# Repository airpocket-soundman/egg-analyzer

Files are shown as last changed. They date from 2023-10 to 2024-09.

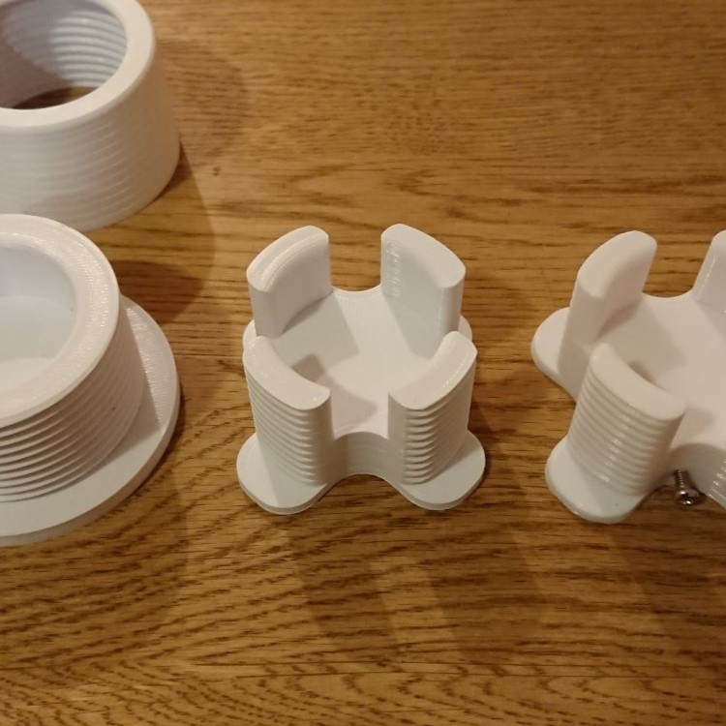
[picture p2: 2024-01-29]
img/DSC_0784_.jpg

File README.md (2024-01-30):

# egg-analyzer
卵の茹で加減を非破壊分析します。

# 開発環境
開発はArduino IDE 2.2.1を使用します。  
使用するライブラリ類は以下の通りです。  

LovyanGFX 1.1.9  

## LovyanGFX
spresenseでLovyanGFXを使用する際にはspresense向けのclass設定をインクルードする必要があります。  
LovyanGFXライブラリ内の/src/lgfx_user/LGFX_SPRESENSE_sample.hppに、spresenseでILI9341という液晶ディスプレイを使用する設定が用意されていますので今回はこれを使用します。  
設定ファイルをインクルードするには、LGFX_SPRESENSE_sample.hppをプロジェクトフォルダに事前にコピーするか、インストールしたフォルダのpathを指定します。  
ここでは、LGFX_SPRESENSE_sample.hppをプロジェクトフォルダ内にコピーして使用します。  

# Hardware

BOM
|名前|数量|備考|
|-|-|-|
|SPRESENSE メインボード|1|(switch science)[https://www.switch-science.com/products/3900]|
|SPRESENSE 拡張ボード|1|(switch science)[https://www.switch-science.com/products/3901]|
|ILI9341 2.2" TFT LCD|1|amazonなどから|
|A4988 ドライバボード|1|amazonなどから|
|Nema17 HS4023|1|[秋月電子](https://akizukidenshi.com/catalog/g/g105372/)|
|M5Stack用電流計ユニット|1|(switch science)[https://www.switch-science.com/products/6739]|
|60mmx80mm ユニバーサル基板|1||
|M2x10 ボルト|8|基板固定用|
|M3x5 皿ボルト|4|ステッピングモーター固定用|
|M3x10 ボルト|6|トップパネル固定用|
|タクトスイッチ|1|[秋月電子](https://akizukidenshi.com/catalog/g/g115660/)|
|φ2.1×φ5.5電源ジャック|1|[秋月電子](https://akizukidenshi.com/catalog/g/g106568/)|
|XHコネクタオス/メス 2P|1||
|XHコネクタオス/メス 3P|1||
|XHコネクタオス/メス 4P|4||
|XHコネクタオス/メス 5P|1||
|QIコネクタオス 2P|1||
|QIコネクタオス 8P|1||
|CASING BASE|1|3Dプリンタ出力※|
|CASING TOP MOTOR|1|3Dプリンタ出力※|
|CASING TOP DISPLAY|1|3Dプリンタ出力※|
|EGG HOLDER BASE|1|3Dプリンタ出力※|
|EGG HOLDER TOP|1|3Dプリンタ出力※|

## Spresense main board

## Spresense extention board
※ILI9431の動作電圧は3V3の為、IO voltage jumperを3V3側に設定する事  
pinout

## ILI9341
※今回使用するILI9431の動作電圧は3V3の為、IO voltage jumperを3V3側に設定する事  
接続図

## A4988 stepper motor driver

## Nema17 stepper motor

## 3D printer parts

## tact switch

# 参考ページ
## steping motor
https://forum.arduino.cc/t/stepper-motor-basics/275223  
https://iot.keicode.com/arduino/arduino-stepper-motor-a4988.php

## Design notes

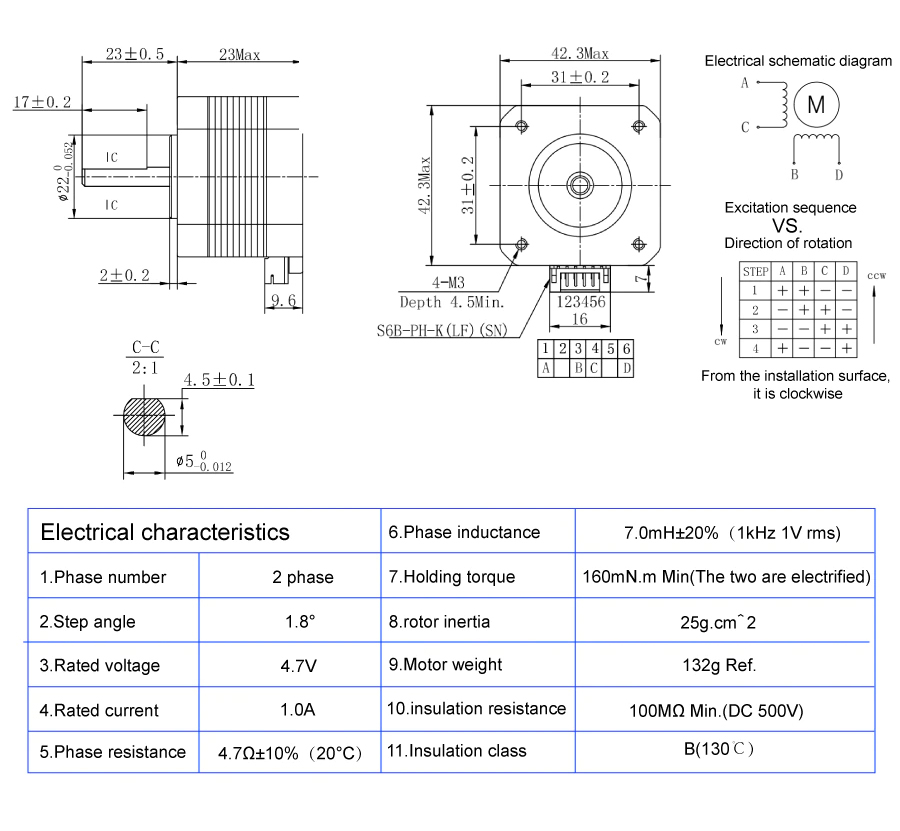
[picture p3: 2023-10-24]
img/Nema17 17HS4023.jpg

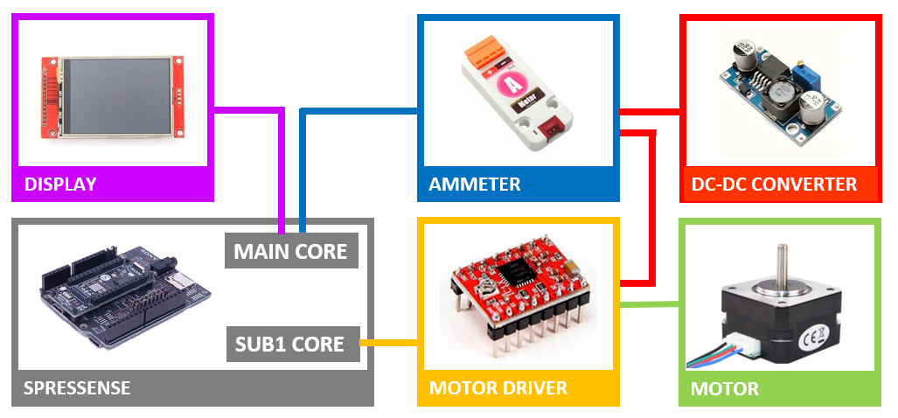
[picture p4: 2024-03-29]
img/構成図.png

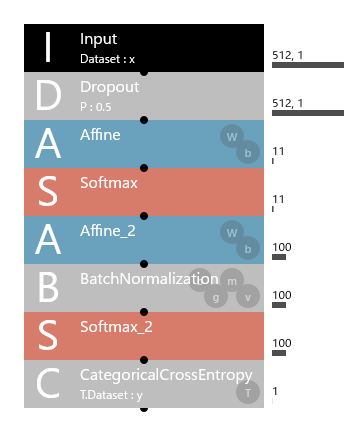
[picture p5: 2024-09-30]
NNC/rawfiles/20240128学習用最終データ/3class_onsen.files/20240128_211929/network.png

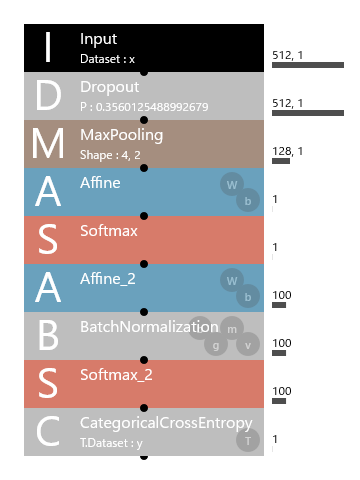
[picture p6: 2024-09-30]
NNC/rawfiles/20240128学習用最終データ/3class_onsen.files/20240128_223451/network.png

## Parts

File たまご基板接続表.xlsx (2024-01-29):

spressens | A4988 | MOTOR | AMMETER | DISPLAY | SW | V12 | STEPDOWN
RX | STEP
TX | DIR
 | B2 | RED
 | A2 | BLUE
 | A1 | GREEN
 | B1 | BLACK
3.3V | VDD |  | VCC | AREF
GND | GND |  | GND | GND |  | GND | in/out -
 | VMOT |  | -
 | GND
 |  |  | + |  |  | OUT | in +
D15 |  |  | SCL
D14 |  |  | SDA
D13 |  |  |  | SCL
D12 |  |  |  | MISO
D11 |  |  |  | MOSI
D10 |  |  |  | CS
D09 |  |  |  | DC
D08 |  |  |  | RST
D04 |  |  |  |  | IN
VOUT |  |  |  |  |  |  | out +

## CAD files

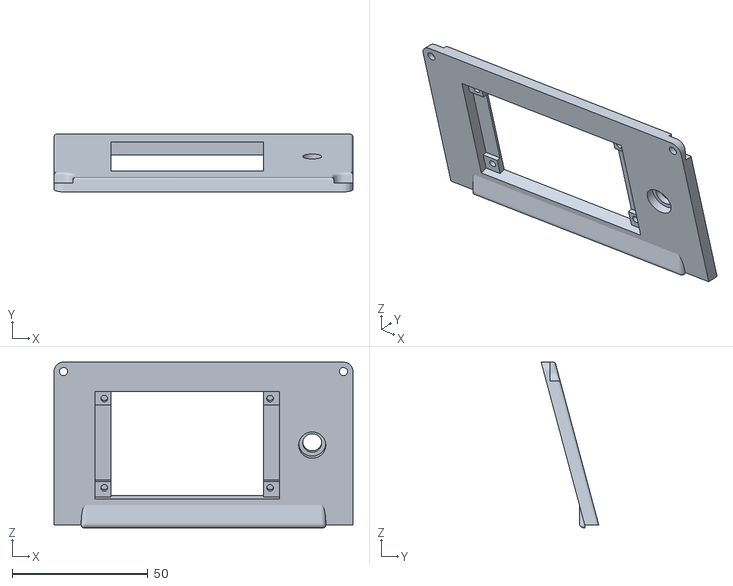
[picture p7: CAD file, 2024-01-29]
stls/top_display v5.stl
110.0 x 21.3 x 61.0

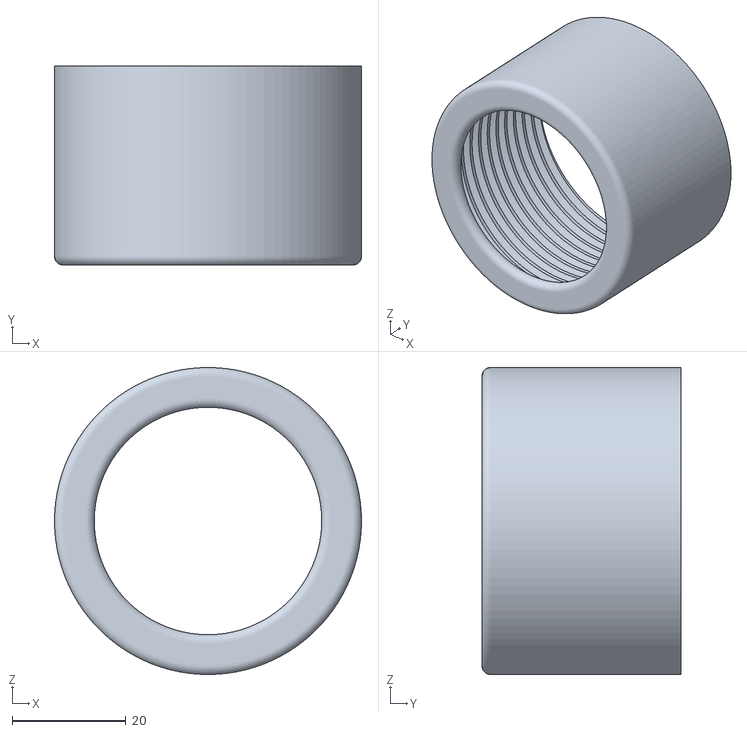
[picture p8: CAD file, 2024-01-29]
stls/egg holoder2 upper v10.stl
54.0 x 35.0 x 54.0

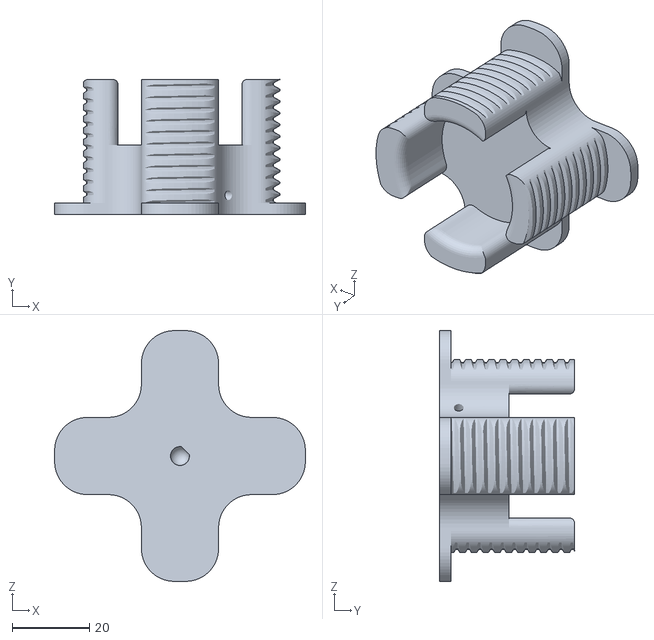
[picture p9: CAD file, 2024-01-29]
stls/egg holder3 v5.stl
65.0 x 35.0 x 65.0

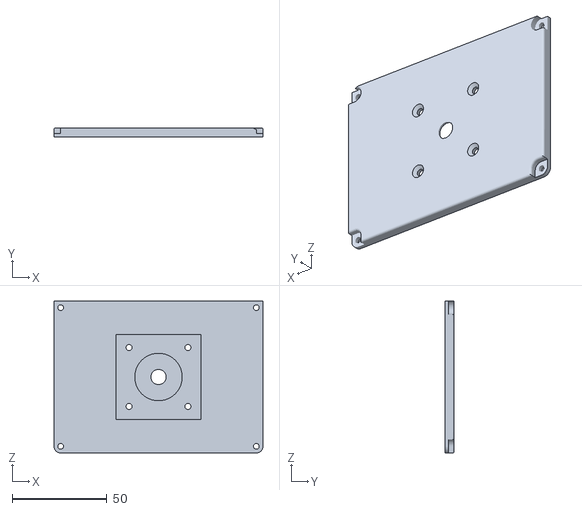
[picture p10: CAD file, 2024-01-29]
stls/top_motor v6.stl
110.0 x 5.00 x 80.0

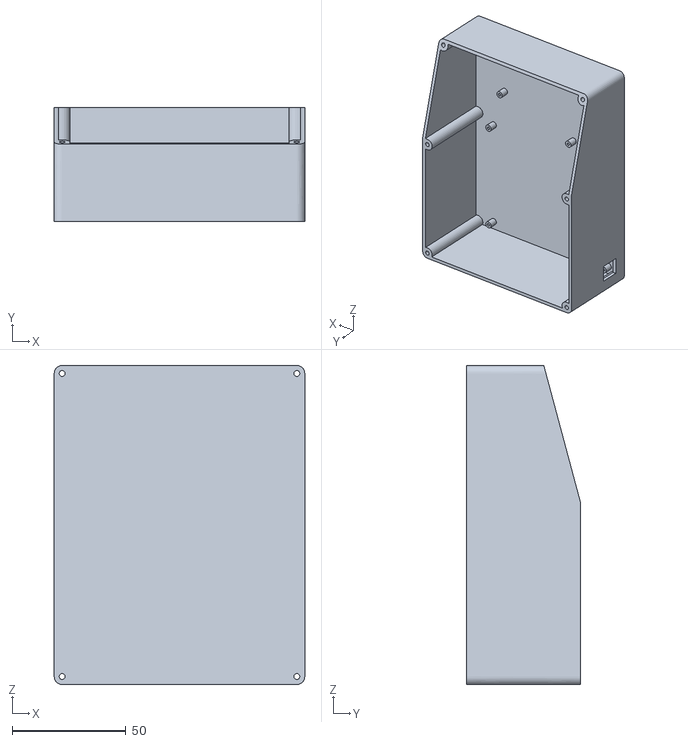
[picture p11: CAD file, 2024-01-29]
stls/case_base v3.stl
110.0 x 50.0 x 140.0

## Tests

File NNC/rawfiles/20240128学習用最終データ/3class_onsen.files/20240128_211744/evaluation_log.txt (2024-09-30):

2024-01-28 22:21:44,733 Evaluation process is started.
python "C:\Users\yamas\Desktop\tools\neural_network_console\libs\Python\Lib\site-packages\nnabla\utils\cli\cli.py" forward
	-c "C:\Users\yamas\Desktop\20240128\3class_onsen.files\20240128_211744\results.nnp"
	-d "C:\Users\yamas\Desktop\20240128\egg_data_set_valid_3class_onsen.csv"
	-o "C:\Users\yamas\Desktop\20240128\3class_onsen.files\20240128_211744"
	--replace_path
2024-01-28 22:21:46,946 [nnabla]: [CALLBACK]: Exec forward on local
2024-01-28 22:21:46,962 [nnabla]: Using context "Context(backend=['cpu:float'], array_class='CpuCachedArray', device_id='')"
2024-01-28 22:21:47,167 [nnabla]: data 64 / 1200
2024-01-28 22:21:47,340 [nnabla]: data 128 / 1200
2024-01-28 22:21:47,524 [nnabla]: data 192 / 1200
2024-01-28 22:21:47,702 [nnabla]: data 256 / 1200
2024-01-28 22:21:47,874 [nnabla]: data 320 / 1200
2024-01-28 22:21:48,051 [nnabla]: data 384 / 1200
2024-01-28 22:21:48,193 [nnabla]: data 448 / 1200
2024-01-28 22:21:48,347 [nnabla]: data 512 / 1200
2024-01-28 22:21:48,526 [nnabla]: data 576 / 1200
2024-01-28 22:21:48,703 [nnabla]: data 640 / 1200
2024-01-28 22:21:48,876 [nnabla]: data 704 / 1200
2024-01-28 22:21:49,050 [nnabla]: data 768 / 1200
2024-01-28 22:21:49,227 [nnabla]: data 832 / 1200
2024-01-28 22:21:49,406 [nnabla]: data 896 / 1200
2024-01-28 22:21:49,584 [nnabla]: data 960 / 1200
2024-01-28 22:21:49,759 [nnabla]: data 1024 / 1200
2024-01-28 22:21:49,936 [nnabla]: data 1088 / 1200
2024-01-28 22:21:50,111 [nnabla]: data 1152 / 1200
2024-01-28 22:21:50,251 [nnabla]: data 1200 / 1200
2024-01-28 22:21:50,267 [nnabla]: Forward Completed.
NNabla command line interface (Version:1.33.1, Build:230206070804, Callback:NNabla SSH callback module.)

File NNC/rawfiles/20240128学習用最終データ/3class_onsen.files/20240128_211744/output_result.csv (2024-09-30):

x:egg_data | y:state | y'__0 | y'__1 | y'__2 | y'__3 | y'__4 | y'__5 | y'__6 | y'__7 | y'__8 | y'__9 | y'__10 | y'__11 | y'__12 | y'__13 | y'__14 | y'__15 | y'__16 | y'__17 | y'__18 | y'__19 | y'__20 | y'__21 | y'__22 | y'__23 | y'__24 | y'__25 | y'__26 | y'__27 | y'__28 | y'__29 | y'__30 | y'__31 | y'__32 | y'__33 | y'__34 | y'__35 | y'__36 | y'__37 | y'__38 | y'__39 | y'__40 | y'__41 | y'__42 | y'__43 | y'__44 | y'__45 | y'__46 | y'__47 | y'__48 | y'__49 | y'__50 | y'__51 | y'__52 | y'__53 | y'__54 | y'__55 | y'__56 | y'__57
C:\Users\yamas\Desktop\20240128\raw0_9x100\fft_060.csv | 0 | 0.92927456 | 0.0018030053 | 0.0022519156 | 0.0006740404 | 0.0006867987 | 0.0007027974 | 0.00068848603 | 0.0006884276 | 0.00069293234 | 0.00069257786 | 0.00067942415 | 0.0006645207 | 0.00069902604 | 0.000694238 | 0.0006832155 | 0.0006840654 | 0.0006793986 | 0.0007164532 | 0.00072102505 | 0.000685254 | 0.00067573186 | 0.00066117983 | 0.00068182714 | 0.0007017419 | 0.00068063627 | 0.00067919196 | 0.0007097714 | 0.0007231526 | 0.0006986092 | 0.00068962516 | 0.00068811513 | 0.00065855443 | 0.00069438835 | 0.00066847424 | 0.00066585414 | 0.0006784439 | 0.0007019413 | 0.00068379496 | 0.00070631824 |
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

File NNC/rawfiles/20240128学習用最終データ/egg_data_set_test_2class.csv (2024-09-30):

x:egg_data | y:state
./raw0_9x100/fft_000.csv | 0
./raw0_9x100/fft_001.csv | 0
./raw0_9x100/fft_002.csv | 0
./raw0_9x100/fft_003.csv | 0
./raw0_9x100/fft_004.csv | 0
./raw0_9x100/fft_005.csv | 0
./raw0_9x100/fft_006.csv | 0
./raw0_9x100/fft_007.csv | 0
./raw0_9x100/fft_008.csv | 0
./raw0_9x100/fft_009.csv | 0
./raw0_9x100/fft_010.csv | 0
./raw0_9x100/fft_011.csv | 0
./raw0_9x100/fft_012.csv | 0
./raw0_9x100/fft_013.csv | 0
./raw0_9x100/fft_014.csv | 0
./raw0_9x100/fft_015.csv | 0
./raw0_9x100/fft_016.csv | 0
./raw0_9x100/fft_017.csv | 0
./raw0_9x100/fft_018.csv | 0
./raw0_9x100/fft_019.csv | 0
./raw0_9x100/fft_020.csv | 0
./raw0_9x100/fft_021.csv | 0
./raw0_9x100/fft_022.csv | 0
./raw0_9x100/fft_023.csv | 0
./raw0_9x100/fft_024.csv | 0
./raw0_9x100/fft_025.csv | 0
./raw0_9x100/fft_026.csv | 0
./raw0_9x100/fft_027.csv | 0
./raw0_9x100/fft_028.csv | 0
./raw0_9x100/fft_029.csv | 0
./raw0_9x100/fft_030.csv | 0
./raw0_9x100/fft_031.csv | 0
./raw0_9x100/fft_032.csv | 0
./raw0_9x100/fft_033.csv | 0
./raw0_9x100/fft_034.csv | 0
./raw0_9x100/fft_035.csv | 0
./raw0_9x100/fft_036.csv | 0
./raw0_9x100/fft_037.csv | 0
./raw0_9x100/fft_038.csv | 0
./raw0_9x100/fft_039.csv | 0
./raw0_9x100/fft_040.csv | 0
./raw0_9x100/fft_041.csv | 0
./raw0_9x100/fft_042.csv | 0
./raw0_9x100/fft_043.csv | 0
./raw0_9x100/fft_044.csv | 0
./raw0_9x100/fft_045.csv | 0
./raw0_9x100/fft_046.csv | 0
./raw0_9x100/fft_047.csv | 0
./raw0_9x100/fft_048.csv | 0
./raw0_9x100/fft_049.csv | 0
./raw0_9x100/fft_050.csv | 0
./raw0_9x100/fft_051.csv | 0
./raw0_9x100/fft_052.csv | 0
./raw0_9x100/fft_053.csv | 0
./raw0_9x100/fft_054.csv | 0
./raw0_9x100/fft_055.csv | 0
./raw0_9x100/fft_056.csv | 0
./raw0_9x100/fft_057.csv | 0
./raw0_9x100/fft_058.csv | 0
./raw0_9x100/fft_059.csv | 0
./raw0_9x100/fft_100.csv | 0
./raw0_9x100/fft_101.csv | 0
./raw0_9x100/fft_102.csv | 0
./raw0_9x100/fft_103.csv | 0
./raw0_9x100/fft_104.csv | 0
./raw0_9x100/fft_105.csv | 0
./raw0_9x100/fft_106.csv | 0
./raw0_9x100/fft_107.csv | 0
./raw0_9x100/fft_108.csv | 0
./raw0_9x100/fft_109.csv | 0
./raw0_9x100/fft_110.csv | 0
./raw0_9x100/fft_111.csv | 0
./raw0_9x100/fft_112.csv | 0
./raw0_9x100/fft_113.csv | 0
./raw0_9x100/fft_114.csv | 0
./raw0_9x100/fft_115.csv | 0
./raw0_9x100/fft_116.csv | 0
./raw0_9x100/fft_117.csv | 0
./raw0_9x100/fft_118.csv | 0
./raw0_9x100/fft_119.csv | 0
./raw0_9x100/fft_120.csv | 0
./raw0_9x100/fft_121.csv | 0
./raw0_9x100/fft_122.csv | 0
./raw0_9x100/fft_123.csv | 0
./raw0_9x100/fft_124.csv | 0
./raw0_9x100/fft_125.csv | 0
./raw0_9x100/fft_126.csv | 0
./raw0_9x100/fft_127.csv | 0
./raw0_9x100/fft_128.csv | 0
./raw0_9x100/fft_129.csv | 0
./raw0_9x100/fft_130.csv | 0
./raw0_9x100/fft_131.csv | 0
./raw0_9x100/fft_132.csv | 0
./raw0_9x100/fft_133.csv | 0
./raw0_9x100/fft_134.csv | 0
./raw0_9x100/fft_135.csv | 0
./raw0_9x100/fft_136.csv | 0
./raw0_9x100/fft_137.csv | 0
./raw0_9x100/fft_138.csv | 0
./raw0_9x100/fft_139.csv | 0
./raw0_9x100/fft_140.csv | 0
./raw0_9x100/fft_141.csv | 0
./raw0_9x100/fft_142.csv | 0
./raw0_9x100/fft_143.csv | 0
./raw0_9x100/fft_144.csv | 0
./raw0_9x100/fft_145.csv | 0
./raw0_9x100/fft_146.csv | 0
./raw0_9x100/fft_147.csv | 0
./raw0_9x100/fft_148.csv | 0
./raw0_9x100/fft_149.csv | 0
./raw0_9x100/fft_150.csv | 0
./raw0_9x100/fft_151.csv | 0
./raw0_9x100/fft_152.csv | 0
./raw0_9x100/fft_153.csv | 0
./raw0_9x100/fft_154.csv | 0
./raw0_9x100/fft_155.csv | 0
./raw0_9x100/fft_156.csv | 0
./raw0_9x100/fft_157.csv | 0
./raw0_9x100/fft_158.csv | 0
./raw0_9x100/fft_159.csv | 0
./raw0_9x100/fft_200.csv | 0
./raw0_9x100/fft_201.csv | 0
./raw0_9x100/fft_202.csv | 0
./raw0_9x100/fft_203.csv | 0
./raw0_9x100/fft_204.csv | 0
./raw0_9x100/fft_205.csv | 0
./raw0_9x100/fft_206.csv | 0
./raw0_9x100/fft_207.csv | 0
./raw0_9x100/fft_208.csv | 0
./raw0_9x100/fft_209.csv | 0
./raw0_9x100/fft_210.csv | 0
./raw0_9x100/fft_211.csv | 0
./raw0_9x100/fft_212.csv | 0
./raw0_9x100/fft_213.csv | 0
./raw0_9x100/fft_214.csv | 0
./raw0_9x100/fft_215.csv | 0
./raw0_9x100/fft_216.csv | 0
./raw0_9x100/fft_217.csv | 0
./raw0_9x100/fft_218.csv | 0
./raw0_9x100/fft_219.csv | 0
./raw0_9x100/fft_220.csv | 0
./raw0_9x100/fft_221.csv | 0
./raw0_9x100/fft_222.csv | 0
./raw0_9x100/fft_223.csv | 0
./raw0_9x100/fft_224.csv | 0
./raw0_9x100/fft_225.csv | 0
./raw0_9x100/fft_226.csv | 0
./raw0_9x100/fft_227.csv | 0
./raw0_9x100/fft_228.csv | 0
./raw0_9x100/fft_229.csv | 0
./raw0_9x100/fft_230.csv | 0
./raw0_9x100/fft_231.csv | 0
./raw0_9x100/fft_232.csv | 0
./raw0_9x100/fft_233.csv | 0
./raw0_9x100/fft_234.csv | 0
./raw0_9x100/fft_235.csv | 0
./raw0_9x100/fft_236.csv | 0
./raw0_9x100/fft_237.csv | 0
./raw0_9x100/fft_238.csv | 0
./raw0_9x100/fft_239.csv | 0
./raw0_9x100/fft_240.csv | 0
./raw0_9x100/fft_241.csv | 0
./raw0_9x100/fft_242.csv | 0
./raw0_9x100/fft_243.csv | 0
./raw0_9x100/fft_244.csv | 0
./raw0_9x100/fft_245.csv | 0
./raw0_9x100/fft_246.csv | 0
./raw0_9x100/fft_247.csv | 0
./raw0_9x100/fft_248.csv | 0
./raw0_9x100/fft_249.csv | 0
./raw0_9x100/fft_250.csv | 0
./raw0_9x100/fft_251.csv | 0
./raw0_9x100/fft_252.csv | 0
./raw0_9x100/fft_253.csv | 0
./raw0_9x100/fft_254.csv | 0
./raw0_9x100/fft_255.csv | 0
./raw0_9x100/fft_256.csv | 0
./raw0_9x100/fft_257.csv | 0
./raw0_9x100/fft_258.csv | 0
./raw0_9x100/fft_259.csv | 0
./raw0_9x100/fft_300.csv | 0
./raw0_9x100/fft_301.csv | 0
./raw0_9x100/fft_302.csv | 0
./raw0_9x100/fft_303.csv | 0
./raw0_9x100/fft_304.csv | 0
./raw0_9x100/fft_305.csv | 0
./raw0_9x100/fft_306.csv | 0
./raw0_9x100/fft_307.csv | 0
./raw0_9x100/fft_308.csv | 0
./raw0_9x100/fft_309.csv | 0
./raw0_9x100/fft_310.csv | 0
./raw0_9x100/fft_311.csv | 0
./raw0_9x100/fft_312.csv | 0
./raw0_9x100/fft_313.csv | 0
./raw0_9x100/fft_314.csv | 0
./raw0_9x100/fft_315.csv | 0
./raw0_9x100/fft_316.csv | 0
./raw0_9x100/fft_317.csv | 0
./raw0_9x100/fft_318.csv | 0
./raw0_9x100/fft_319.csv | 0
./raw0_9x100/fft_320.csv | 0
./raw0_9x100/fft_321.csv | 0
./raw0_9x100/fft_322.csv | 0
./raw0_9x100/fft_323.csv | 0
./raw0_9x100/fft_324.csv | 0
./raw0_9x100/fft_325.csv | 0
./raw0_9x100/fft_326.csv | 0
./raw0_9x100/fft_327.csv | 0
./raw0_9x100/fft_328.csv | 0
./raw0_9x100/fft_329.csv | 0
./raw0_9x100/fft_330.csv | 0
./raw0_9x100/fft_331.csv | 0
./raw0_9x100/fft_332.csv | 0
./raw0_9x100/fft_333.csv | 0
./raw0_9x100/fft_334.csv | 0
./raw0_9x100/fft_335.csv | 0
./raw0_9x100/fft_336.csv | 0
./raw0_9x100/fft_337.csv | 0
./raw0_9x100/fft_338.csv | 0
./raw0_9x100/fft_339.csv | 0
./raw0_9x100/fft_340.csv | 0
./raw0_9x100/fft_341.csv | 0
./raw0_9x100/fft_342.csv | 0
./raw0_9x100/fft_343.csv | 0
./raw0_9x100/fft_344.csv | 0
./raw0_9x100/fft_345.csv | 0
./raw0_9x100/fft_346.csv | 0
./raw0_9x100/fft_347.csv | 0
./raw0_9x100/fft_348.csv | 0
./raw0_9x100/fft_349.csv | 0
./raw0_9x100/fft_350.csv | 0
./raw0_9x100/fft_351.csv | 0
./raw0_9x100/fft_352.csv | 0
./raw0_9x100/fft_353.csv | 0
./raw0_9x100/fft_354.csv | 0
./raw0_9x100/fft_355.csv | 0
./raw0_9x100/fft_356.csv | 0
./raw0_9x100/fft_357.csv | 0
./raw0_9x100/fft_358.csv | 0
./raw0_9x100/fft_359.csv | 0
./raw0_9x100/fft_400.csv | 0
./raw0_9x100/fft_401.csv | 0
./raw0_9x100/fft_402.csv | 0
./raw0_9x100/fft_403.csv | 0
./raw0_9x100/fft_404.csv | 0
./raw0_9x100/fft_405.csv | 0
./raw0_9x100/fft_406.csv | 0
./raw0_9x100/fft_407.csv | 0
./raw0_9x100/fft_408.csv | 0
./raw0_9x100/fft_409.csv | 0
./raw0_9x100/fft_410.csv | 0
./raw0_9x100/fft_411.csv | 0
./raw0_9x100/fft_412.csv | 0
./raw0_9x100/fft_413.csv | 0
./raw0_9x100/fft_414.csv | 0
./raw0_9x100/fft_415.csv | 0
./raw0_9x100/fft_416.csv | 0
./raw0_9x100/fft_417.csv | 0
./raw0_9x100/fft_418.csv | 0
./raw0_9x100/fft_419.csv | 0
./raw0_9x100/fft_420.csv | 0
./raw0_9x100/fft_421.csv | 0
./raw0_9x100/fft_422.csv | 0
./raw0_9x100/fft_423.csv | 0
./raw0_9x100/fft_424.csv | 0
./raw0_9x100/fft_425.csv | 0
./raw0_9x100/fft_426.csv | 0
./raw0_9x100/fft_427.csv | 0
./raw0_9x100/fft_428.csv | 0
./raw0_9x100/fft_429.csv | 0
./raw0_9x100/fft_430.csv | 0
./raw0_9x100/fft_431.csv | 0
./raw0_9x100/fft_432.csv | 0
./raw0_9x100/fft_433.csv | 0
./raw0_9x100/fft_434.csv | 0
./raw0_9x100/fft_435.csv | 0
./raw0_9x100/fft_436.csv | 0
./raw0_9x100/fft_437.csv | 0
./raw0_9x100/fft_438.csv | 0
./raw0_9x100/fft_439.csv | 0
./raw0_9x100/fft_440.csv | 0
./raw0_9x100/fft_441.csv | 0
./raw0_9x100/fft_442.csv | 0
./raw0_9x100/fft_443.csv | 0
./raw0_9x100/fft_444.csv | 0
./raw0_9x100/fft_445.csv | 0
./raw0_9x100/fft_446.csv | 0
./raw0_9x100/fft_447.csv | 0
./raw0_9x100/fft_448.csv | 0
./raw0_9x100/fft_449.csv | 0
./raw0_9x100/fft_450.csv | 0
./raw0_9x100/fft_451.csv | 0
./raw0_9x100/fft_452.csv | 0
./raw0_9x100/fft_453.csv | 0
./raw0_9x100/fft_454.csv | 0
./raw0_9x100/fft_455.csv | 0
./raw0_9x100/fft_456.csv | 0
./raw0_9x100/fft_457.csv | 0
./raw0_9x100/fft_458.csv | 0
./raw0_9x100/fft_459.csv | 0
./raw0_9x100/fft_500.csv | 0
./raw0_9x100/fft_501.csv | 0
./raw0_9x100/fft_502.csv | 0
./raw0_9x100/fft_503.csv | 0
./raw0_9x100/fft_504.csv | 0
./raw0_9x100/fft_505.csv | 0
./raw0_9x100/fft_506.csv | 0
./raw0_9x100/fft_507.csv | 0
./raw0_9x100/fft_508.csv | 0
./raw0_9x100/fft_509.csv | 0
./raw0_9x100/fft_510.csv | 0
./raw0_9x100/fft_511.csv | 0
./raw0_9x100/fft_512.csv | 0
./raw0_9x100/fft_513.csv | 0
./raw0_9x100/fft_514.csv | 0
./raw0_9x100/fft_515.csv | 0
./raw0_9x100/fft_516.csv | 0
./raw0_9x100/fft_517.csv | 0
./raw0_9x100/fft_518.csv | 0
./raw0_9x100/fft_519.csv | 0
./raw0_9x100/fft_520.csv | 0
./raw0_9x100/fft_521.csv | 0
./raw0_9x100/fft_522.csv | 0
./raw0_9x100/fft_523.csv | 0
./raw0_9x100/fft_524.csv | 0
./raw0_9x100/fft_525.csv | 0
./raw0_9x100/fft_526.csv | 0
./raw0_9x100/fft_527.csv | 0
./raw0_9x100/fft_528.csv | 0
./raw0_9x100/fft_529.csv | 0
./raw0_9x100/fft_530.csv | 0
./raw0_9x100/fft_531.csv | 0
./raw0_9x100/fft_532.csv | 0
./raw0_9x100/fft_533.csv | 0
./raw0_9x100/fft_534.csv | 0
./raw0_9x100/fft_535.csv | 0
./raw0_9x100/fft_536.csv | 0
./raw0_9x100/fft_537.csv | 0
./raw0_9x100/fft_538.csv | 0
./raw0_9x100/fft_539.csv | 0
./raw0_9x100/fft_540.csv | 0
./raw0_9x100/fft_541.csv | 0
./raw0_9x100/fft_542.csv | 0
./raw0_9x100/fft_543.csv | 0
./raw0_9x100/fft_544.csv | 0
./raw0_9x100/fft_545.csv | 0
./raw0_9x100/fft_546.csv | 0
./raw0_9x100/fft_547.csv | 0
./raw0_9x100/fft_548.csv | 0
./raw0_9x100/fft_549.csv | 0
./raw0_9x100/fft_550.csv | 0
./raw0_9x100/fft_551.csv | 0
./raw0_9x100/fft_552.csv | 0
./raw0_9x100/fft_553.csv | 0
./raw0_9x100/fft_554.csv | 0
./raw0_9x100/fft_555.csv | 0
./raw0_9x100/fft_556.csv | 0
./raw0_9x100/fft_557.csv | 0
./raw0_9x100/fft_558.csv | 0
./raw0_9x100/fft_559.csv | 0
./raw0_9x100/fft_600.csv | 0
./raw0_9x100/fft_601.csv | 0
./raw0_9x100/fft_602.csv | 0
./raw0_9x100/fft_603.csv | 0
./raw0_9x100/fft_604.csv | 0
./raw0_9x100/fft_605.csv | 0
./raw0_9x100/fft_606.csv | 0
./raw0_9x100/fft_607.csv | 0
./raw0_9x100/fft_608.csv | 0
./raw0_9x100/fft_609.csv | 0
./raw0_9x100/fft_610.csv | 0
./raw0_9x100/fft_611.csv | 0
./raw0_9x100/fft_612.csv | 0
./raw0_9x100/fft_613.csv | 0
./raw0_9x100/fft_614.csv | 0
./raw0_9x100/fft_615.csv | 0
./raw0_9x100/fft_616.csv | 0
./raw0_9x100/fft_617.csv | 0
./raw0_9x100/fft_618.csv | 0
./raw0_9x100/fft_619.csv | 0
./raw0_9x100/fft_620.csv | 0
./raw0_9x100/fft_621.csv | 0
./raw0_9x100/fft_622.csv | 0
./raw0_9x100/fft_623.csv | 0
./raw0_9x100/fft_624.csv | 0
./raw0_9x100/fft_625.csv | 0
./raw0_9x100/fft_626.csv | 0
./raw0_9x100/fft_627.csv | 0
./raw0_9x100/fft_628.csv | 0
./raw0_9x100/fft_629.csv | 0
./raw0_9x100/fft_630.csv | 0
./raw0_9x100/fft_631.csv | 0
./raw0_9x100/fft_632.csv | 0
./raw0_9x100/fft_633.csv | 0
./raw0_9x100/fft_634.csv | 0
./raw0_9x100/fft_635.csv | 0
./raw0_9x100/fft_636.csv | 0
./raw0_9x100/fft_637.csv | 0
./raw0_9x100/fft_638.csv | 0
./raw0_9x100/fft_639.csv | 0
./raw0_9x100/fft_640.csv | 0
./raw0_9x100/fft_641.csv | 0
./raw0_9x100/fft_642.csv | 0
./raw0_9x100/fft_643.csv | 0
./raw0_9x100/fft_644.csv | 0
./raw0_9x100/fft_645.csv | 0
./raw0_9x100/fft_646.csv | 0
./raw0_9x100/fft_647.csv | 0
./raw0_9x100/fft_648.csv | 0
./raw0_9x100/fft_649.csv | 0
./raw0_9x100/fft_650.csv | 0
./raw0_9x100/fft_651.csv | 0
./raw0_9x100/fft_652.csv | 0
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

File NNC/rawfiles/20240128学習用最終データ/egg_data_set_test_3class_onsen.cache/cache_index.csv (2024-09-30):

cache_00000000_00000099.npy | 100
cache_00000100_00000199.npy | 100
cache_00000200_00000299.npy | 100
cache_00000300_00000399.npy | 100
cache_00000400_00000499.npy | 100
cache_00000500_00000599.npy | 100
cache_00000600_00000699.npy | 100
cache_00000700_00000799.npy | 100
cache_00000800_00000899.npy | 100
cache_00000900_00000999.npy | 100
cache_00001000_00001099.npy | 100
cache_00001100_00001199.npy | 100
cache_00001200_00001299.npy | 100
cache_00001300_00001399.npy | 100
cache_00001400_00001499.npy | 100
cache_00001500_00001599.npy | 100
cache_00001600_00001699.npy | 100
cache_00001700_00001799.npy | 100

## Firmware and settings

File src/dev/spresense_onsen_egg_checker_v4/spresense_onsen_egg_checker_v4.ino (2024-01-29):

//subcore1 : spresense_stepper_ameter_subcore_v5.ino

#ifdef SUBCORE
#error "Core selection is wrong!!"
#endif

#include <Arduino.h>
#include <Wire.h>
#include "arduinoFFT.h"

#include <MP.h>
int subcore1   = 1;               //使用するサブコア

#include "LGFX_SPRESENSE_sample.hpp"
static LGFX lcd;                  //ディスプレイインスタンス作成


#include <DNNRT.h>
DNNRT dnnrt;

#include <SDHCI.h>
#include <Flash.h>
SDClass SD;                       /**< SDClass object */ 
File nnbFile;
File myFile;

//ファイル保存用変数
int number = 0;       //測定の通し番号

// 測定条件
#define TOTAL_MESUREMENTS   1024    //測定回数
#define MESUREMENT_CYCLE    2500    //測定頻度 us秒/回
#define MESURE_START_DELAY  250000   //モータースタートから測定開始までのディレイタイム　usec
int freq = 1000000 / MESUREMENT_CYCLE;

//FFT用
double vReal[TOTAL_MESUREMENTS];  // vReal[]にサンプリングしたデーターを入れる
double vImag[TOTAL_MESUREMENTS];  // 虚数部
arduinoFFT FFT = arduinoFFT(vReal, vImag, TOTAL_MESUREMENTS, freq);  // FFTオブジェクトを作る


#include "ammeter.h"
Ammeter ammeter;                  /**Ameter object**/
double am_value[TOTAL_MESUREMENTS];
int elapsed_time[TOTAL_MESUREMENTS];

//gpio 定義
const int SW1Pin = 4;
const int SW2Pin = 6;
const int SW3Pin = 5;
const int SW4Pin = 7;
const int SW5Pin = 3;

//switch state管理用
int SW1State    = LOW;
int SW2State    = LOW;
int SW3State    = LOW;
int SW4State    = LOW;
int SW5State    = LOW;
int SW1StateOld = LOW;
int SW2StateOld = LOW;
int SW3StateOld = LOW;
int SW4StateOld = LOW;
int SW5StateOld = LOW;

void setup() {
//nnb file open
  SD.begin();
  nnbFile = SD.open("model.nnb");                     //学習済みデータ読み込み
  if (!nnbFile) {
    Serial.println("model.nnb is not found");
    while(1);
  }
  
  int ret = dnnrt.begin(nnbFile);
  if (ret <0){
    Serial.println("DNNRT begin fail: " + String(ret));
    while(1);
  }

  Wire.begin();                 //i2cを有効化
  Wire.setClock(1000000);       //standart mode:100000, fast mode:400000, fast mode plus:1000000, high speed mode:3400000
  Serial.begin(115200);         //USBシリアル通信を有効化

  ret = 0;
  ret = MP.begin(subcore1);                           //subcore1を起動
  if (ret < 0) {                                      //subcore起動失敗時の表示
    MPLog("MP.begin(%d) error = %d\n", 1, ret);
  }

  //ameter 設定
  ammeter.setMode(SINGLESHOT);
  ammeter.setRate(RATE_860);    //8,16,32,64,128(defo),250,475,860
  ammeter.setGain(PAG_2048);
//  hope = page512_volt / ammeter.resolution;
  // | PAG      | Max Input Voltage(V) |
  // | PAG_6144 |        128           |
  // | PAG_4096 |        64            |
  // | PAG_2048 |        32            |
  // | PAG_512  |        16            |
  // | PAG_256  |        8             |

  //Switch pin 設定
  pinMode(SW1Pin, INPUT_PULLUP);
  pinMode(SW2Pin, INPUT_PULLUP);
  pinMode(SW3Pin, INPUT_PULLUP);
  pinMode(SW4Pin, INPUT_PULLUP);
  pinMode(SW5Pin, INPUT_PULLUP);

  lcd.init();                       //ili9431を初期化
  lcd.setRotation(1);               //右へ90°回転
  lcd.setFont(&fonts::Font0);
}

void loop() {

  SW1StateOld = SW1State;
  SW1State = digitalRead(SW1Pin);
  SW2StateOld = SW2State;
  SW2State = digitalRead(SW2Pin);
  SW3StateOld = SW3State;
  SW3State = digitalRead(SW3Pin);
  SW4StateOld = SW4State;
  SW4State = digitalRead(SW4Pin);
  SW5StateOld = SW5State;
  SW5State = digitalRead(SW5Pin);

  lcd.setCursor(0,0);


  if (SW1State == LOW && SW1StateOld == HIGH){
    lcd.printf("Currently measuring                              \n");

    mesure_current();
    for(int i = 0; i < TOTAL_MESUREMENTS; i++){
      am_value[i] = vReal[i];
    }

    DCRemoval(vReal, TOTAL_MESUREMENTS);                                 //直流成分除去
    FFT.Windowing(FFT_WIN_TYP_HAMMING, FFT_FORWARD);  // 窓関数
    FFT.Compute(FFT_FORWARD);                         // FFT処理(複素数で計算)
    FFT.ComplexToMagnitude();                         // 複素数を実数に変換    
    Serial.println("normalization");
    normalization(vReal, TOTAL_MESUREMENTS);
    normalization(am_value, TOTAL_MESUREMENTS);    
    //drawGraph(am_value); 
    drawGraph(vReal);
    saveData();


    //推論実行
    DNNVariable input(TOTAL_MESUREMENTS/2);
    float* data = input.data();
    for (int i = 0; i < TOTAL_MESUREMENTS/2; ++i){
      data[i] = vReal[i];
    }
    dnnrt.inputVariable(input, 0);
    dnnrt.forward();
    DNNVariable output = dnnrt.outputVariable(0);

    lcd.setCursor(0,20);
    lcd.printf("\nMax Index = ");
    lcd.println(output.maxIndex());
    
    Serial.println(output.maxIndex());
    Serial.print("\noutput.maxIndex()=");
    Serial.println(output[output.maxIndex()]);
    for (int i = 0; i < 3; i++){
      Serial.println(output[i]);
      lcd.printf("\ni:");
      lcd.print(i);
      lcd.printf("  value:");
      lcd.print(output[i]);
    }
    lcd.setCursor(0,220);

    lcd.setFont(&fonts::Font4);
    if (output.maxIndex() == 0){
      lcd.print("This is RAW EGG.");
    } else if (output.maxIndex() == 1){
      lcd.print("This is ONSEN EGG!");
    } else if (output.maxIndex() == 2){
      lcd.print("This is BOILED EGG.");
    }
    lcd.setFont(&fonts::Font0);

  } else if (SW1State == HIGH && SW1StateOld == LOW) {
    lcd.printf("set TAMAGO and push start SW");
  }
}

void drawGraph(double *data){
  lcd.fillScreen(lcd.color888(0, 0, 0));
  double max = data[0];
  double min = data[0];
  for (int i = 0; i < TOTAL_MESUREMENTS; i++ ){
    if (data[i] > max) max = data[i];
    if (data[i] < min) min = data[i];
  }

  int graph_size_x = 320;
  int graph_size_y = 200;
  int y0 = graph_size_y - 0;
  int y1;
  int x1;
  for (int i = 0; i < TOTAL_MESUREMENTS/2; i++ ){
    if (i + 1 < graph_size_x){
      x1 = i;
    }else if(i >= graph_size_x){
      x1 = i % graph_size_x;
    }
    y1 = int(graph_size_y - data[i] / (max - min) * graph_size_y);
    if(i > 0){
      lcd.drawLine(x1 - 1, y0, x1, y1, lcd.color888(0, 255, 0));
    }
    y0 = y1;
  }
}


void DCRemoval(double *vData, int sample_num) {
    double mean = 0;
    for (uint16_t i = 1; i < sample_num; i++) {
        mean += vData[i];
    }
    mean /= sample_num;
    for (uint16_t i = 1; i < sample_num; i++) {
        vData[i] -= mean;
    }
}

void mesure_current(){
  double current;
  int now;
  int old;
  int elapsedTime;

  int ret = MP.Send(3,50000,subcore1);
  delayMicroseconds(MESURE_START_DELAY);    //測定開始までのdelay
  Serial.println("start mesure cycle");
  for(int i = 0; i < TOTAL_MESUREMENTS; i++){
//    Serial.printf("cycle num = %d / ",i);
    if (i == 0){
      now = micros();
      current = ammeter.getCurrent();
      
    } else {
      old = now;
      elapsedTime = now - old; 
      while(elapsedTime <= MESUREMENT_CYCLE){
        now = micros();
        elapsedTime = now - old;
      }
      current = ammeter.getCurrent();
      old = now;
    }
//    Serial.println(elapsedTime);
    elapsed_time[i]  = elapsedTime;
    vReal[i] = current;
    vImag[i] = 0;
  }
  Serial.println(elapsedTime);
}


void normalization (double *data, int sample_num){
  double minValue = data[0];
  double maxValue = data[0];

  for (int i = 0; i < sample_num; i++) {
    if (data[i] < minValue) {
      minValue = data[i];
    }
    if (data[i] > maxValue) {
      maxValue = data[i];
    }
  }
  for (int i = 0; i < sample_num; i++) {
    data[i] = (data[i] - minValue) / (maxValue - minValue);
  }

}


void saveData(){
  SD.begin();
  char fname[16];
  sprintf(fname, "fft_%03d.csv", number);
  myFile = SD.open(fname,FILE_WRITE);
  if (!myFile){
    Serial.println("SD Open Error: "+String(fname));
    return;
  }

  for (int i = 0; i < TOTAL_MESUREMENTS / 2; i++){
    myFile.println(vReal[i]);
  }
  myFile.close();

  sprintf(fname, "am_%03d.csv", number);
  myFile = SD.open(fname,FILE_WRITE);
  if (!myFile){
    Serial.println("SD Open Error: "+String(fname));
    return;
  }

  for (int i = 1; i < TOTAL_MESUREMENTS; i++){
    myFile.println(am_value[i]);
  }
  myFile.close();

  //lcd.setCursor(0,220);
  //lcd.printf("number %d saved",number);

  number++;
}

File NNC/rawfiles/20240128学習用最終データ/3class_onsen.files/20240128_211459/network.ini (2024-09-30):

[Engine]
SDeepEngineType=NNabla
[Network_Global]
NumLayer=7
NumLink=6
[Layer_0]
ID=0
Type=Input
Position_0=24
Position_1=24
Position_2=240
Position_3=48
Property_0_Name=Name
Property_0_Value=Input
Property_1_Name=Size
Property_1_Value=512,1
Property_2_Name=Dataset
Property_2_Value=x
Property_3_Name=Generator
Property_3_Value=None
Property_4_Name=GeneratorMultiplier
Property_4_Value=1.0
Property_5_Name=Order
Property_5_Value=-1
NumProperty=6
[Layer_1]
ID=1
Type=Affine
Position_0=24
Position_1=72
Position_2=240
Position_3=48
Property_0_Name=Name
Property_0_Value=Affine
Property_1_Name=OutShape
Property_1_Value=77
Property_2_Name=WithBias
Property_2_Value=True
Property_3_Name=ParameterScope
Property_3_Value=*Name
Property_4_Name=W.File
Property_4_Value=
Property_5_Name=W.Initializer
Property_5_Value=NormalAffineGlorot
Property_6_Name=W.InitializerMultiplier
Property_6_Value=1.0
Property_7_Name=W.LRateMultiplier
Property_7_Value=1.0
Property_8_Name=b.File
Property_8_Value=
Property_9_Name=b.Initializer
Property_9_Value=Constant
Property_10_Name=b.InitializerMultiplier
Property_10_Value=0.0
Property_11_Name=b.LRateMultiplier
Property_11_Value=1.0
NumProperty=12
[Layer_2]
ID=2
Type=Softmax
Position_0=24
Position_1=120
Position_2=240
Position_3=48
Property_0_Name=Name
Property_0_Value=Softmax
Property_1_Name=Axis
Property_1_Value=0
NumProperty=2
[Layer_3]
ID=3
Type=Softmax
Position_0=24
Position_1=264
Position_2=240
Position_3=48
Property_0_Name=Name
Property_0_Value=Softmax_2
Property_1_Name=Axis
Property_1_Value=0
NumProperty=2
[Layer_4]
ID=4
Type=Affine
Position_0=24
Position_1=168
Position_2=240
Position_3=48
Property_0_Name=Name
Property_0_Value=Affine_2
Property_1_Name=OutShape
Property_1_Value=100
Property_2_Name=WithBias
Property_2_Value=True
Property_3_Name=ParameterScope
Property_3_Value=*Name
Property_4_Name=W.File
Property_4_Value=
Property_5_Name=W.Initializer
Property_5_Value=NormalAffineGlorot
Property_6_Name=W.InitializerMultiplier
Property_6_Value=1.0
Property_7_Name=W.LRateMultiplier
Property_7_Value=1.0
Property_8_Name=b.File
Property_8_Value=
Property_9_Name=b.Initializer
Property_9_Value=Constant
Property_10_Name=b.InitializerMultiplier
Property_10_Value=0.0
Property_11_Name=b.LRateMultiplier
Property_11_Value=1.0
NumProperty=12
[Layer_5]
ID=5
Type=CategoricalCrossEntropy
Position_0=24
Position_1=312
Position_2=240
Position_3=48
Property_0_Name=Name
Property_0_Value=CategoricalCrossEntropy
Property_1_Name=Axis
Property_1_Value=0
Property_2_Name=T.Dataset
Property_2_Value=y
Property_3_Name=T.Generator
Property_3_Value=None
Property_4_Name=T.GeneratorMultiplier
Property_4_Value=1.0
NumProperty=5
[Layer_6]
ID=6
Type=BatchNormalization
Position_0=24
Position_1=216
Position_2=240
Position_3=48
Property_0_Name=Name
Property_0_Value=BatchNormalization
Property_1_Name=Axes
Property_1_Value=0
Property_2_Name=DecayRate
Property_2_Value=0.9
Property_3_Name=Epsilon
Property_3_Value=0.0001
Property_4_Name=BatchStat
Property_4_Value=True
Property_5_Name=ParameterScope
Property_5_Value=*Name
Property_6_Name=beta.File
Property_6_Value=
Property_7_Name=beta.Initializer
Property_7_Value=Constant
Property_8_Name=beta.InitializerMultiplier
Property_8_Value=0.0
Property_9_Name=beta.LRateMultiplier
Property_9_Value=1.0
Property_10_Name=gamma.File
Property_10_Value=
Property_11_Name=gamma.Initializer
Property_11_Value=Constant
Property_12_Name=gamma.InitializerMultiplier
Property_12_Value=1.0
Property_13_Name=gamma.LRateMultiplier
Property_13_Value=1.0
Property_14_Name=mean.File
Property_14_Value=
Property_15_Name=mean.Initializer
Property_15_Value=Constant
Property_16_Name=mean.InitializerMultiplier
Property_16_Value=0.0
Property_17_Name=mean.LRateMultiplier
Property_17_Value=0.0
Property_18_Name=var.File
Property_18_Value=
Property_19_Name=var.Initializer
Property_19_Value=Constant
Property_20_Name=var.InitializerMultiplier
Property_20_Value=0.0
Property_21_Name=var.LRateMultiplier
Property_21_Value=0.0
NumProperty=22
[Link_0]
ID=0
SourceLayerID=0
SourcePinIndex=0
DestLayerID=1
DestPinIndex=0
[Link_1]
ID=1
SourceLayerID=1
SourcePinIndex=0
DestLayerID=2
DestPinIndex=0
[Link_2]
ID=2
SourceLayerID=2
SourcePinIndex=0
DestLayerID=4
DestPinIndex=0
[Link_3]
ID=4
SourceLayerID=3
SourcePinIndex=0
DestLayerID=5
DestPinIndex=0
[Link_4]
ID=5
SourceLayerID=4
SourcePinIndex=0
DestLayerID=6
DestPinIndex=0
[Link_5]
ID=6
SourceLayerID=6
SourcePinIndex=0
DestLayerID=3
DestPinIndex=0
[Dataset]
Num=2
MainIndex=0
[Dataset_0]
Name=Training
URI=C:\Users\yamas\Desktop\20240128\egg_data_set_test_3class_onsen.csv
Shuffle=1
EnableCache=0
ImageNormalization=1
NumData=1800
[Dataset_1]
Name=Validation
URI=C:\Users\yamas\Desktop\20240128\egg_data_set_valid_3class_onsen.csv
Shuffle=0
EnableCache=0
ImageNormalization=1
NumData=1200
[Description]
Text=
[Config]
MaxEpoch=100
SaveBest=1
BatchSize=64
TypeConfig=Float
MonitorInterval=10
AutoEvaluation=0
NumOptimizer=1
NumMonitor=2
NumExecutor=1
[Optimizer_0]
RangeFrom=-1
RangeTo=-1
RangeUnit=0
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

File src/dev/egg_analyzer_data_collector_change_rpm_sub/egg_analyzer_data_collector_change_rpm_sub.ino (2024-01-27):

//subcore1にメッセージが届くと、

#if (SUBCORE != 1)
#error "Core selection is wrong!!"
#endif

#include <MP.h>
#include <math.h>

//#define VMAX                    100             //　モーターの最高速　100で1回転/sec相当（ちがうかも  30 100
#define VMAX                    30
#define CYCLETIME               800000          //  Sinカーブに沿って加減速するさいのSin波周期 600000us = 600ms = 0.6sec900000,4000000
//#define CYCLETIME               4000000
#define NUMBER_OF_TIME_SEGMENTS 500             //  sinカーブをこの数値で分周して疑似サインカーブを生成する
#define NUMBER_OF_REPEAT        4               //  sin加速を繰り返す回数
//#define NUMBER_OF_REPEAT        1
#define MOVE_TIME               3000000         //周り続ける時間(us)

const int SW2Pin = 6;
const int DirPin  = 0;
const int StepPin = 1;

void setup()
{
  MP.begin();
  pinMode(DirPin,  OUTPUT);
  pinMode(StepPin, OUTPUT);
  digitalWrite(DirPin,  LOW);
  digitalWrite(StepPin, LOW);
}

void loop()
{
  int      ret;
  int8_t   msgid;
  uint32_t msgdata;

  ret = MP.Recv(&msgid, &msgdata);
  //delayMicroseconds(1000);
  delayMicroseconds(1000);
  int delaytime = 100;
  for (int i = 0; i <= MOVE_TIME / 2 /msgdata; i++){
    //delaytime -= 1;
    //if (delaytime < msgdata){
    //  delaytime = msgdata;
    //}
    stepMotor(delaytime);
  }
  //stepper_move();
}

void stepper_move(){
  digitalWrite(DirPin,  LOW);
  MPLog("stepper start\n");
  int Vmax                 = VMAX;
  int timeCycle            = CYCLETIME;                       //usecの時間で１周期
  int numberOfTimeSegments = NUMBER_OF_TIME_SEGMENTS;         //１周期を何分周するか
  int numberOfRepeat       = NUMBER_OF_REPEAT;                //何周期繰り返すか

  for (int i = 0; i < numberOfRepeat; i++){
    sinAccel(Vmax, numberOfTimeSegments, timeCycle);
  }
}

//回転速度Vの時のdelayTimeを返す　1回転/secをV = 100とした場合のtimedelayを計算（まちがってるかも。
int getTimeDelay(int V){
  if (V != 0){
    return 2500 / abs(V);
  } else {
    return -1;
  }
}

//stepper motorを1step/timeDelay*2マイクロ秒の速度でステップ
void stepMotor(int timeDelay){ 
  digitalWrite(StepPin, HIGH);
  delayMicroseconds(timeDelay);
  digitalWrite(StepPin, LOW);
  delayMicroseconds(timeDelay);
}

//stepper motorをtimeSegmetマイクロ秒の間、1step/timeDelay*2マイクロ秒の速度でステップ
void stepMotorInTimeSegment(int V, int timeSegment){
    
  if (V > 0){
    digitalWrite(DirPin, LOW);
  } else if (V < 0) {
    digitalWrite(DirPin, HIGH);
  }

  if (V != 0){
    int timeDelay = getTimeDelay(V);
    int numberOfSteps = timeSegment / (timeDelay * 2);
    for (int i = 0; i < numberOfSteps; i++){
      stepMotor(timeDelay);
    }
  } else{
    delayMicroseconds(timeSegment);
  }
}

//最高速度Vmaxでsinカーブに沿って加減速する。timeがsinカーブの一周期、一周期をnumberOfTimeSegments回に分周して速度制御する。
void sinAccel(int Vmax, int numberOfTimeSegments, int time){
  int timeSegment = time / numberOfTimeSegments;        //timeSegmet = 単位時間(us)
  for (int i = 1 ; i <= numberOfTimeSegments; i++){
    float phase = i / (float)numberOfTimeSegments;      
    float rad   = phase * 2 * PI;                       //rad = 現在の位相
    int V = sin(rad) * Vmax;                            //V = 現在の位相での速度
    stepMotorInTimeSegment(V, timeSegment);             //timeSegment(us)の間、速度Vでステップさせる。
  }
}

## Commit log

2024-01-29 img,stls,src追加
    [case_base v3.stl, egg holder3 v5.stl, egg holoder2 upper v10.stl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]
2024-01-30 shematicかこうかな
    [connector_board.kicad_sch]
2024-03-29 構成図追加
    [構成図.xlsx]
2024-09-30 開発データ追加
    [am_000.csv, am_001.csv, am_002.csv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]
2025-03-04 Update LGFX_SPRESENSE_sample.hpp
    不要な設定例を削除
